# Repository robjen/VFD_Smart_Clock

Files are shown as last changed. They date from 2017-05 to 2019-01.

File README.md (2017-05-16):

# VFD_Smart_Clock

A Series of 'socket' designs and firmware running on ESP8266 for IoT smart clock

first draft of working firmware :
https://www.youtube.com/watch?v=jQWC35hEyko

Sockets are 1-4 digits in all sorts of size based on:
* 4 digits IV4/17 16 segment tube
* 1 digit 5x7 IV26 7 point tubes type 1 (fully independant dots) and type 3  (1-2-1-2-1 )
* 2 digits 2x 5x7 IV25 7 point tubes type 1 and type 3 (yes found these on the internet named them as above)
* LED lighting under/behind each tube with a WS2812 RGB 
* HV module on each board so they are fully independant and run from a single 5V supply
* 4 digital lines for easy control passed though each board SPI-clk SPI-data SPI-load BLANK LED-data

Any of the types of socket can be chained, but you might have to mess about with the firmware if you want mix-n-match different types

Firmware provides:
* clock display 
* NTP sync
* auto DST based on timezone
* hidden 'phrases'
* RSS news reader (BBC)
* Ability to add user messages
* Web interface for configuration
* a load of animated transitions and effects
* a few LED effects (more coming soon)

loads of new features coming soon

its a bit of a mess right now but in progress

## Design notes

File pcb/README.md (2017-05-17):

# eagle cad files for 5 types of PCB

not the best naming convention but load them to see whats what

all of them have been sent off for manufacture at http://dirtypcbs.com and work

simple layout for easy hand soldering including everything in sockets

I switched convention on the IV25 and started calling them type 1 and type 3 to match the IV26 tubes the PCB mask layer reflects that even if the PCB schematic does not

# Tubes ....

well they are getting harder to find but ebay is your friend, also use the 'international' .com site as I find the UK site sometimes hides possible sellers that will still ship to here and quote prices in dollars

# Components 

the main IC ... you can use that maxim part but its pricey or a perfect substitute is the 'HV5812' again ebay is the place to find those

WS2812b again ebay cheap and easy to find in reels ready to solder, that and 1 capacitor are surface mount (on the IV4/17 board) easy enough with a steady hand

the DC-DC module was again an ebay thing (can you spot a trend here!)  there are loads of far east manufactures doing a module that should be about £1 including post per module.  you could use one module to power more than 1 PCB with a fly-lead thats up to you, keeping 1 module per PCB means you can mix and match anything you want. 

# BIG SOLDER TIP

The hardest part can be threading the tubes and getting them all nice and level.

Note the marker point on each PCB, sometimes this is the short (almost removed) pin, sometimes the longest pin, sometimes just a vague guide ... it will depend where you sourced your tubes from, check and check again before you solder as there is no going back. the PCB layout is as per data sheet but these tubes have an element of 'hand made' so not 100% perfect they should face forward give or take a tiny adjustment.

I found that for tubes with few wires it is easy enough to align them all by hand in one go and push whole tube down in one step.

For tubes with lots of wires (IV4/17) start by threading a few on one side then work round with tweezers loading each wire in turn until you can push the whole tube home.

DO NOT use the glass envelope of the tube to try and align the digits, they vary quite a lot internally so allow a gap above the PCB on the first one you solder and alight the 'dots' or digits by eye or with a rule to get them even. If you dont allow a gap on the first one you might find you cant push subsequent ones down low enough ... 

At this point in construction I tended to tape everything down to a spare board as I went so that all the tubes were well aligned and I can fip it up and solder

KEEP YOUR FIRST EXAMPLE at least the first one you are happy with, then you can use it as a guide of height of dot/digit from the PCB for subsequent builds  (I use a scrap early PCB design that had an error but the tubes are neat so its a good guide).

you can adjust tubes a little once soldered but there is a risk you will break the pins or short something if you try and squash the tubes down. you cant really do more than a tiny twist on the IV4/17 tubes

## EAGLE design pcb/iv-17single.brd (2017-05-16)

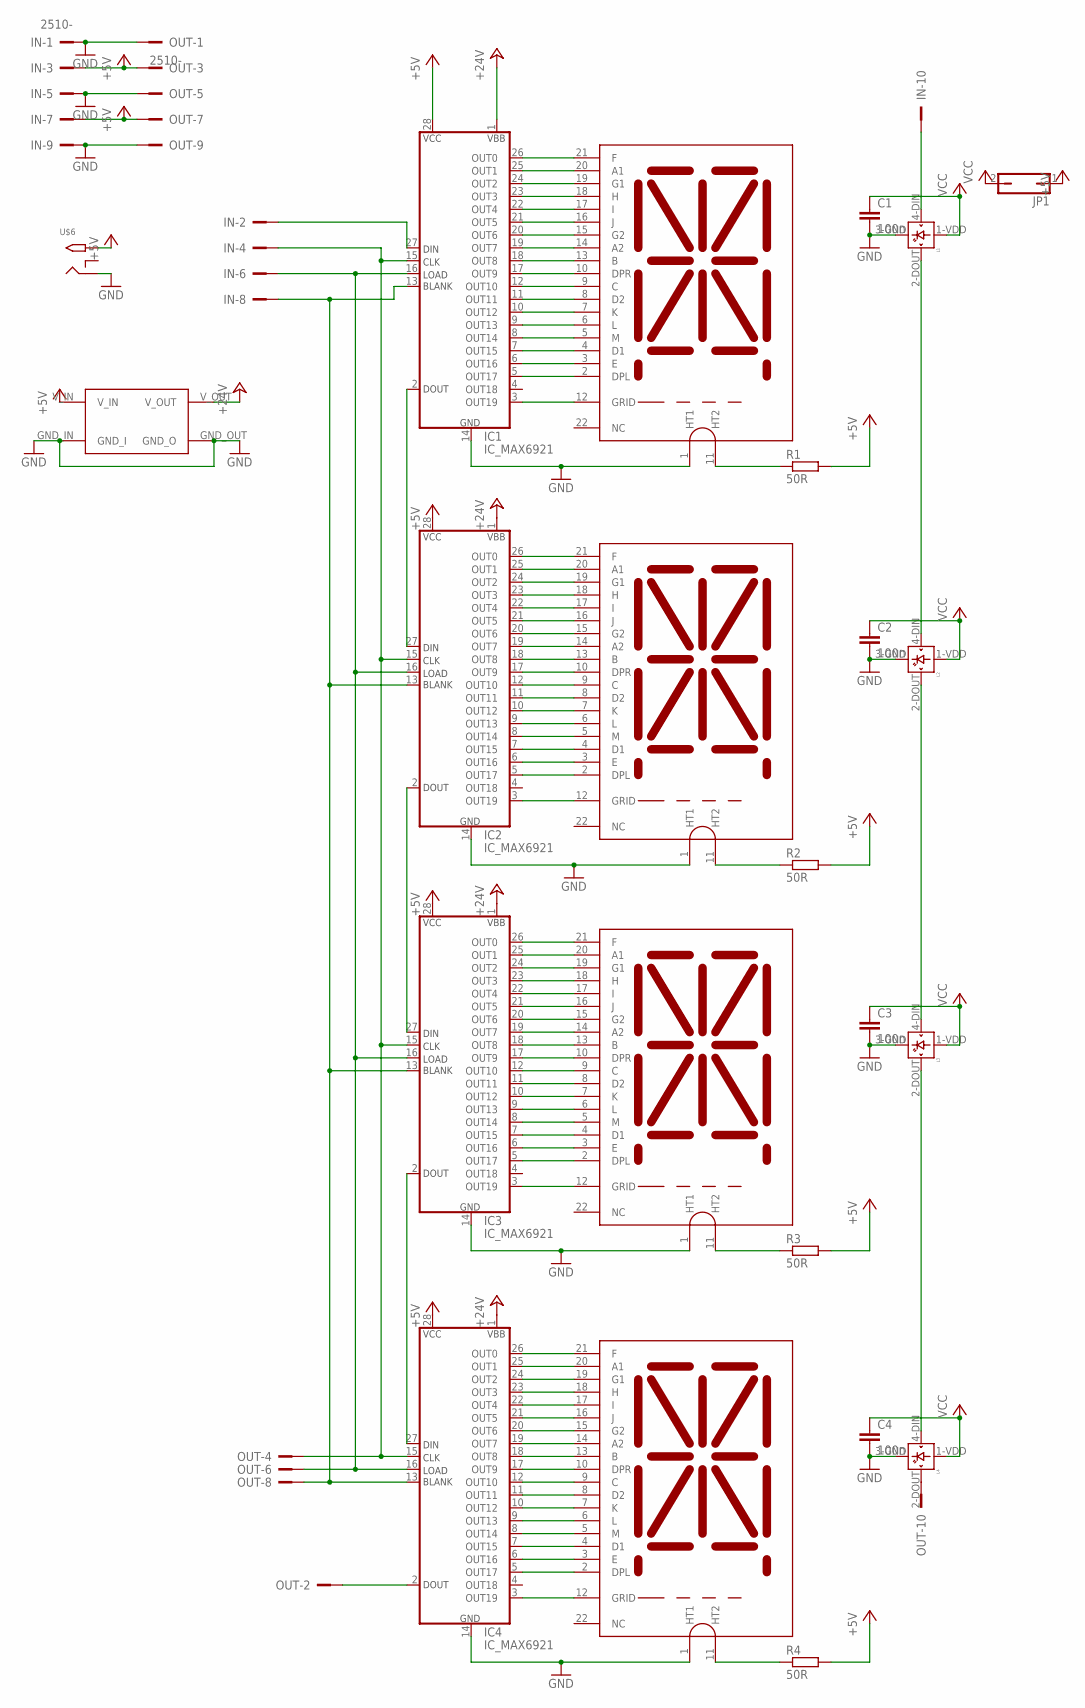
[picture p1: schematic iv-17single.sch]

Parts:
1, 2, 3, 4: IV-17_DISPIV-17; IV-17
C1, C2, C3, C4: 100n; C0805
IC1, IC2, IC3, IC4: IC_MAX6921; S28
IN: 2510-; PAK100/2500-10
JP1: JP1Q; JP1
L1, L2, L3, L4: WS2812B
OUT: 2510-; PAK100/2500-10
R1, R2, R3, R4: 50R; 0207/10
U$5: STEP_UP_MODULE
U$6: 2.1MMJACKTHM; PJ-102A

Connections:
+5V: IC1.28 (VCC), IC2.28 (VCC), IC3.28 (VCC), IC4.28 (VCC), IN.3, IN.7, JP1.1, OUT.3, OUT.7, R1.2, R2.2, R3.2, R4.2, U$5.V_IN, U$6.TIP
+24V: IC1.1 (VBB), IC2.1 (VBB), IC3.1 (VBB), IC4.1 (VBB), U$5.V_OUT
GND: 1.1 (HT1), 2.1 (HT1), 3.1 (HT1), 4.1 (HT1), C1.2, C2.2, C3.2, C4.2, IC1.14 (GND), IC2.14 (GND), IC3.14 (GND), IC4.14 (GND), IN.1, IN.5, IN.9, L1.3-GND (GND), L2.3-GND (GND), L3.3-GND (GND), L4.3-GND (GND), OUT.1, OUT.5, OUT.9, U$5.GND_IN (GND_I), U$5.GND_OUT (GND_O), U$6.RING
unnamed: 1.11 (HT2), R1.1
unnamed: 1.21 (F), IC1.26 (OUT0)
unnamed: 1.20 (A1), IC1.25 (OUT1)
unnamed: 1.19 (G1), IC1.24 (OUT2)
unnamed: 1.18 (H), IC1.23 (OUT3)
unnamed: 1.17 (I), IC1.22 (OUT4)
unnamed: 1.16 (J), IC1.21 (OUT5)
unnamed: 1.15 (G2), IC1.20 (OUT6)
unnamed: 1.14 (A2), IC1.19 (OUT7)
unnamed: 1.13 (B), IC1.18 (OUT8)
unnamed: 1.10 (DPR), IC1.17 (OUT9)
unnamed: 1.9 (C), IC1.12 (OUT10)
unnamed: 1.8 (D2), IC1.11 (OUT11)
unnamed: 1.7 (K), IC1.10 (OUT12)
unnamed: 1.6 (L), IC1.9 (OUT13)
unnamed: 1.5 (M), IC1.8 (OUT14)
unnamed: 1.4 (D1), IC1.7 (OUT15)
unnamed: 1.3 (E), IC1.6 (OUT16)
unnamed: 1.2 (DPL), IC1.5 (OUT17)
unnamed: 1.12 (GRID), IC1.3 (OUT19)
unnamed: IC1.27 (DIN), IN.2
unnamed: IC4.2 (DOUT), OUT.2
unnamed: 2.21 (F), IC2.26 (OUT0)
unnamed: L1.2-DOUT (DOUT), L2.4-DIN (DIN)
unnamed: IC1.2 (DOUT), IC2.27 (DIN)
unnamed: 2.20 (A1), IC2.25 (OUT1)
unnamed: 2.19 (G1), IC2.24 (OUT2)
unnamed: 2.18 (H), IC2.23 (OUT3)
unnamed: 2.17 (I), IC2.22 (OUT4)
unnamed: 2.16 (J), IC2.21 (OUT5)
unnamed: 2.15 (G2), IC2.20 (OUT6)
unnamed: 2.14 (A2), IC2.19 (OUT7)
unnamed: 2.13 (B), IC2.18 (OUT8)
unnamed: 2.10 (DPR), IC2.17 (OUT9)
unnamed: 2.9 (C), IC2.12 (OUT10)
unnamed: IC1.15 (CLK), IC2.15 (CLK), IC3.15 (CLK), IC4.15 (CLK), IN.4, OUT.4
unnamed: 2.8 (D2), IC2.11 (OUT11)
unnamed: 2.7 (K), IC2.10 (OUT12)
unnamed: 2.6 (L), IC2.9 (OUT13)
unnamed: 2.5 (M), IC2.8 (OUT14)
unnamed: 2.4 (D1), IC2.7 (OUT15)
unnamed: 2.3 (E), IC2.6 (OUT16)
unnamed: 2.2 (DPL), IC2.5 (OUT17)
unnamed: 2.12 (GRID), IC2.3 (OUT19)
unnamed: IC1.16 (LOAD), IC2.16 (LOAD), IC3.16 (LOAD), IC4.16 (LOAD), IN.6, OUT.6
unnamed: 2.11 (HT2), R2.1
unnamed: 3.21 (F), IC3.26 (OUT0)
unnamed: 3.20 (A1), IC3.25 (OUT1)
unnamed: 3.19 (G1), IC3.24 (OUT2)
unnamed: 3.18 (H), IC3.23 (OUT3)
unnamed: 3.17 (I), IC3.22 (OUT4)
unnamed: 3.16 (J), IC3.21 (OUT5)
unnamed: 3.15 (G2), IC3.20 (OUT6)
unnamed: 3.14 (A2), IC3.19 (OUT7)
unnamed: 3.13 (B), IC3.18 (OUT8)
unnamed: 3.10 (DPR), IC3.17 (OUT9)
unnamed: 3.9 (C), IC3.12 (OUT10)
unnamed: 3.8 (D2), IC3.11 (OUT11)
unnamed: 3.7 (K), IC3.10 (OUT12)
unnamed: 3.6 (L), IC3.9 (OUT13)
unnamed: 3.5 (M), IC3.8 (OUT14)
unnamed: 3.4 (D1), IC3.7 (OUT15)
unnamed: 3.3 (E), IC3.6 (OUT16)
unnamed: 3.2 (DPL), IC3.5 (OUT17)
unnamed: 3.12 (GRID), IC3.3 (OUT19)
unnamed: IC1.13 (BLANK), IC2.13 (BLANK), IC3.13 (BLANK), IC4.13 (BLANK), IN.8, OUT.8
unnamed: 3.11 (HT2), R3.1
unnamed: 4.21 (F), IC4.26 (OUT0)
unnamed: 4.20 (A1), IC4.25 (OUT1)
unnamed: 4.19 (G1), IC4.24 (OUT2)
unnamed: 4.18 (H), IC4.23 (OUT3)
unnamed: 4.17 (I), IC4.22 (OUT4)
unnamed: 4.16 (J), IC4.21 (OUT5)
unnamed: 4.15 (G2), IC4.20 (OUT6)
unnamed: 4.14 (A2), IC4.19 (OUT7)
unnamed: 4.13 (B), IC4.18 (OUT8)
unnamed: 4.10 (DPR), IC4.17 (OUT9)
unnamed: 4.9 (C), IC4.12 (OUT10)
unnamed: 4.8 (D2), IC4.11 (OUT11)
unnamed: 4.7 (K), IC4.10 (OUT12)
unnamed: 4.6 (L), IC4.9 (OUT13)
unnamed: 4.5 (M), IC4.8 (OUT14)
unnamed: 4.4 (D1), IC4.7 (OUT15)
unnamed: 4.3 (E), IC4.6 (OUT16)
unnamed: 4.2 (DPL), IC4.5 (OUT17)
unnamed: 4.12 (GRID), IC4.3 (OUT19)
unnamed: L2.2-DOUT (DOUT), L3.4-DIN (DIN)
unnamed: 4.11 (HT2), R4.1
unnamed: L3.2-DOUT (DOUT), L4.4-DIN (DIN)
unnamed: IN.10, L1.4-DIN (DIN)
unnamed: L4.2-DOUT (DOUT), OUT.10
unnamed: IC2.2 (DOUT), IC3.27 (DIN)
unnamed: IC3.2 (DOUT), IC4.27 (DIN)
VCC: C1.1, C2.1, C3.1, C4.1, JP1.2, L1.1-VDD (VDD), L2.1-VDD (VDD), L3.1-VDD (VDD), L4.1-VDD (VDD)

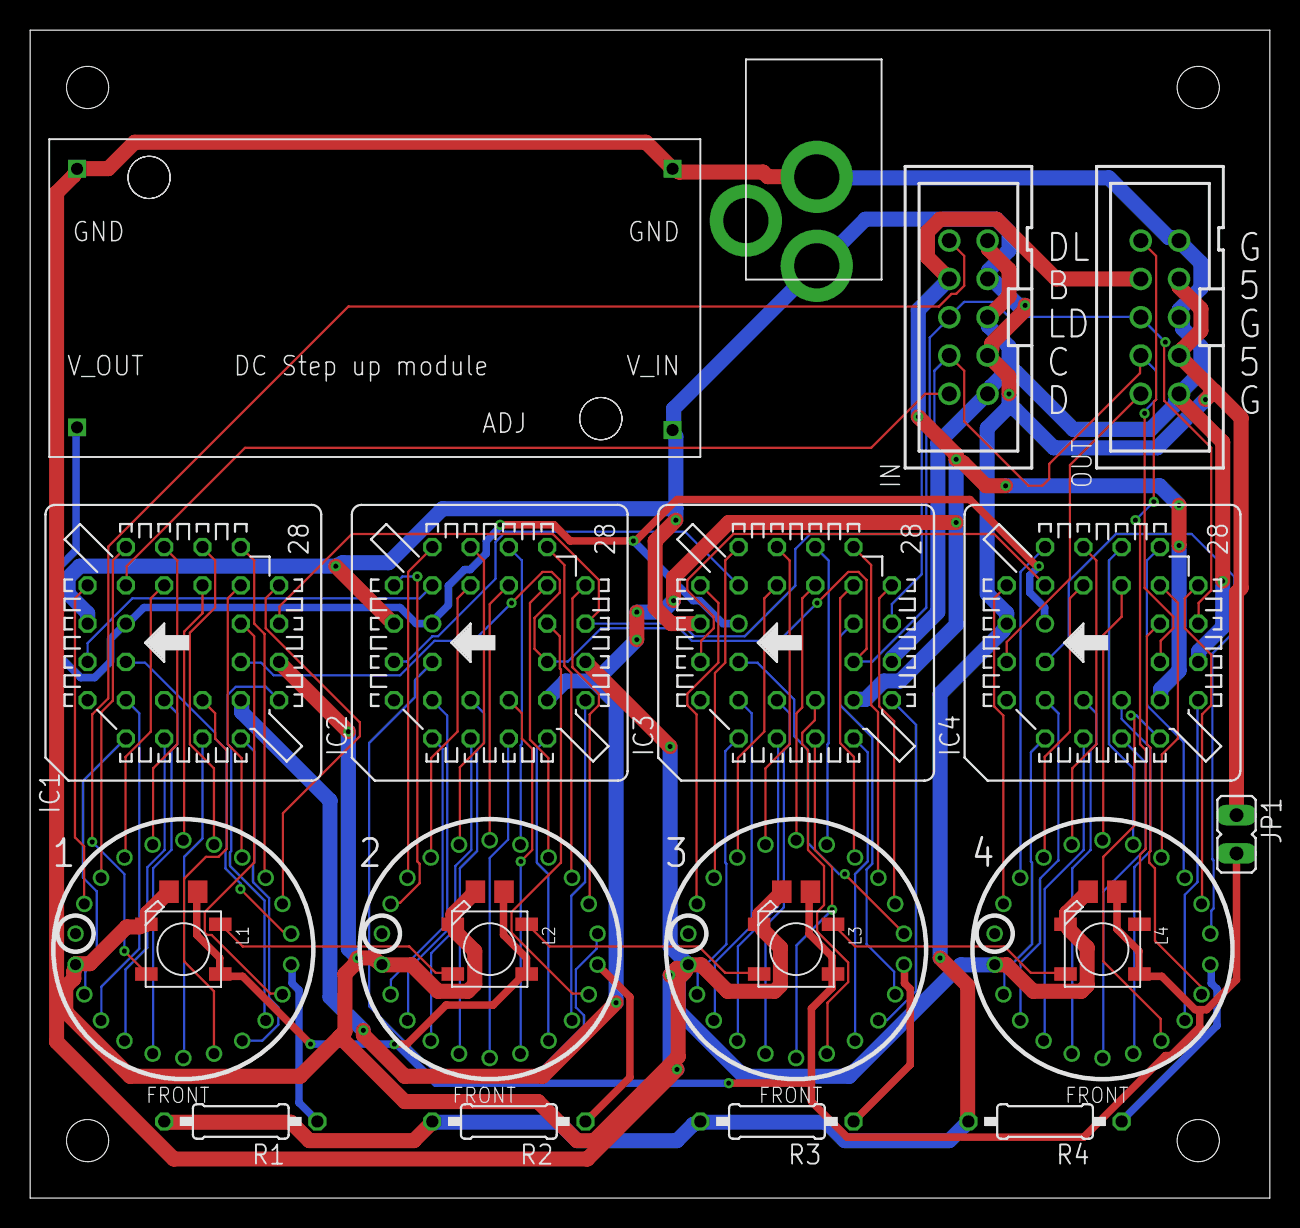
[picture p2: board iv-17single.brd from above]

Board: 2 copper layers, 82.2 x 77.5 mm, 25 parts (0 on the bottom side), 97 nets.

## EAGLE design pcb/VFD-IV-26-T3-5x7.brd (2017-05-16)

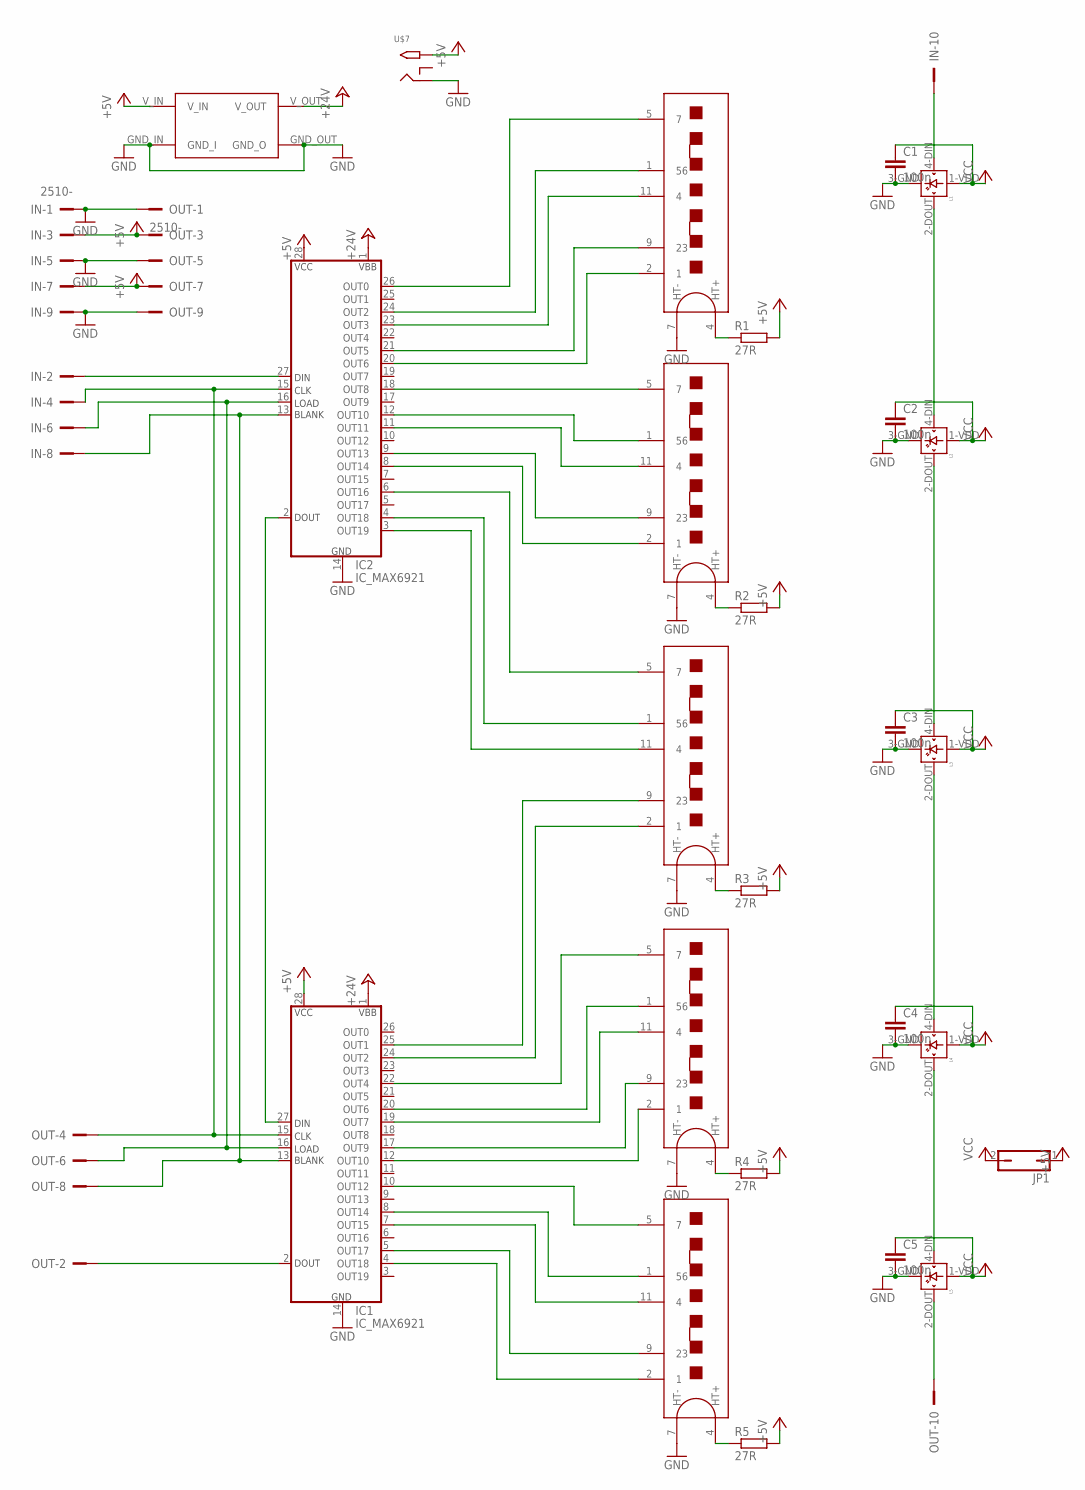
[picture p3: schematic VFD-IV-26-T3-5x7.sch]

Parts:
1, 2, 3, 4, 5: IV-26-T3_DISP; IV-26_T2_T3
C1, C2, C3, C4, C5: 100n; C050-025X075
IC1, IC2: IC_MAX6921; S28
IN: 2510-; PAK100/2500-10
JP1: JP1Q; JP1
L1, L2, L3, L4, L5: WS2812B
OUT: 2510-; PAK100/2500-10
R1, R2, R3, R4, R5: 27R; 0207/10
U$6: STEP_UP_MODULE
U$7: 2.1MMJACKTHM; PJ-102A

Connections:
+5V: IC1.28 (VCC), IC2.28 (VCC), IN.3, IN.7, JP1.1, OUT.3, OUT.7, R1.2, R2.2, R3.2, R4.2, R5.2, U$6.V_IN, U$7.TIP
+24V: IC1.1 (VBB), IC2.1 (VBB), U$6.V_OUT
GND: 1.7 (HT-), 2.7 (HT-), 3.7 (HT-), 4.7 (HT-), 5.7 (HT-), C1.2, C2.2, C3.2, C4.2, C5.2, IC1.14 (GND), IC2.14 (GND), IN.1, IN.5, IN.9, L1.3-GND (GND), L2.3-GND (GND), L3.3-GND (GND), L4.3-GND (GND), L5.3-GND (GND), OUT.1, OUT.5, OUT.9, U$6.GND_IN (GND_I), U$6.GND_OUT (GND_O), U$7.RING
unnamed: 1.5 (7), IC2.26 (OUT0)
unnamed: 1.1 (56), IC2.24 (OUT2)
unnamed: 1.11 (4), IC2.23 (OUT3)
unnamed: 1.9 (23), IC2.21 (OUT5)
unnamed: 1.2 (1), IC2.20 (OUT6)
unnamed: 2.5 (7), IC2.18 (OUT8)
unnamed: 2.1 (56), IC2.12 (OUT10)
unnamed: 2.11 (4), IC2.11 (OUT11)
unnamed: 2.9 (23), IC2.9 (OUT13)
unnamed: 2.2 (1), IC2.8 (OUT14)
unnamed: 3.5 (7), IC2.6 (OUT16)
unnamed: 3.1 (56), IC2.4 (OUT18)
unnamed: 3.11 (4), IC2.3 (OUT19)
unnamed: 3.9 (23), IC1.25 (OUT1)
unnamed: 3.2 (1), IC1.24 (OUT2)
unnamed: 4.5 (7), IC1.22 (OUT4)
unnamed: 4.1 (56), IC1.20 (OUT6)
unnamed: 4.11 (4), IC1.19 (OUT7)
unnamed: 4.9 (23), IC1.17 (OUT9)
unnamed: 4.2 (1), IC1.12 (OUT10)
unnamed: 5.5 (7), IC1.10 (OUT12)
unnamed: 5.1 (56), IC1.8 (OUT14)
unnamed: 5.11 (4), IC1.7 (OUT15)
unnamed: 5.9 (23), IC1.5 (OUT17)
unnamed: 5.2 (1), IC1.4 (OUT18)
unnamed: L1.2-DOUT (DOUT), L2.4-DIN (DIN)
unnamed: L2.2-DOUT (DOUT), L3.4-DIN (DIN)
unnamed: L3.2-DOUT (DOUT), L4.4-DIN (DIN)
unnamed: L4.2-DOUT (DOUT), L5.4-DIN (DIN)
unnamed: IC1.15 (CLK), IC2.15 (CLK), IN.4, OUT.4
unnamed: IC1.27 (DIN), IC2.2 (DOUT)
unnamed: IC1.13 (BLANK), IC2.13 (BLANK), IN.8, OUT.8
unnamed: IC1.16 (LOAD), IC2.16 (LOAD), IN.6, OUT.6
unnamed: IC2.27 (DIN), IN.2
unnamed: IN.10, L1.4-DIN (DIN)
unnamed: 2.4 (HT+), R2.1
unnamed: 3.4 (HT+), R3.1
unnamed: 4.4 (HT+), R4.1
unnamed: 5.4 (HT+), R5.1
unnamed: 1.4 (HT+), R1.1
unnamed: IC1.2 (DOUT), OUT.2
unnamed: L5.2-DOUT (DOUT), OUT.10
VCC: C1.1, C2.1, C3.1, C4.1, C5.1, JP1.2, L1.1-VDD (VDD), L2.1-VDD (VDD), L3.1-VDD (VDD), L4.1-VDD (VDD), L5.1-VDD (VDD)

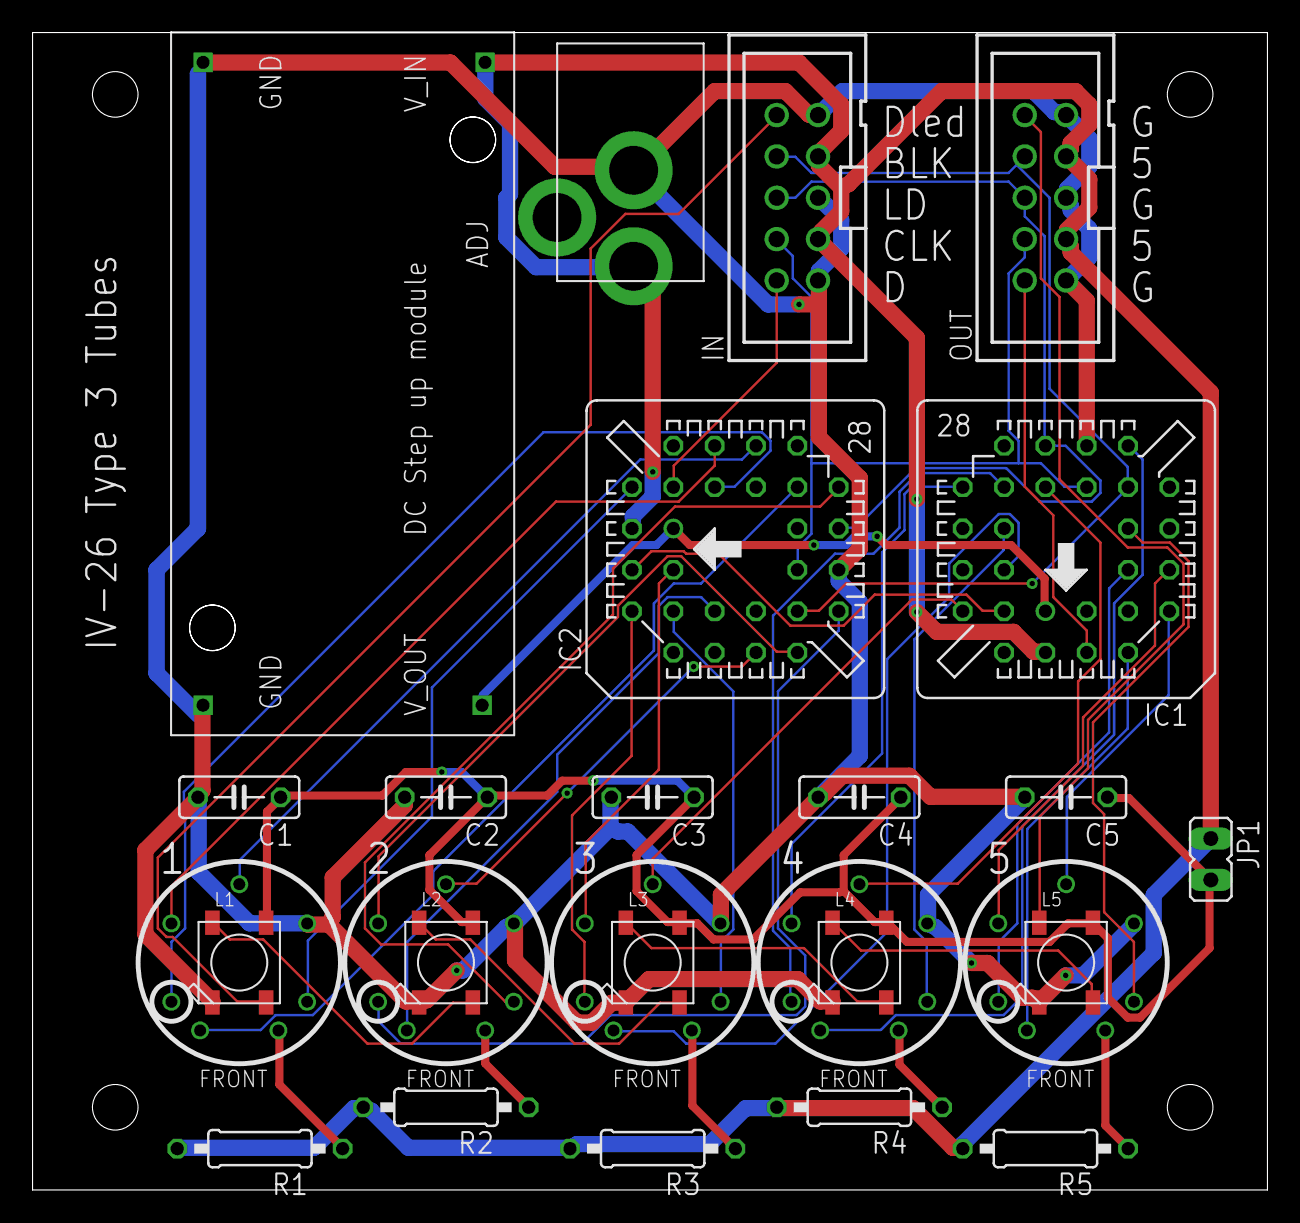
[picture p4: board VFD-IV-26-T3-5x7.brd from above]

Board: 2 copper layers, 75.9 x 71.1 mm, 27 parts (0 on the bottom side), 46 nets.

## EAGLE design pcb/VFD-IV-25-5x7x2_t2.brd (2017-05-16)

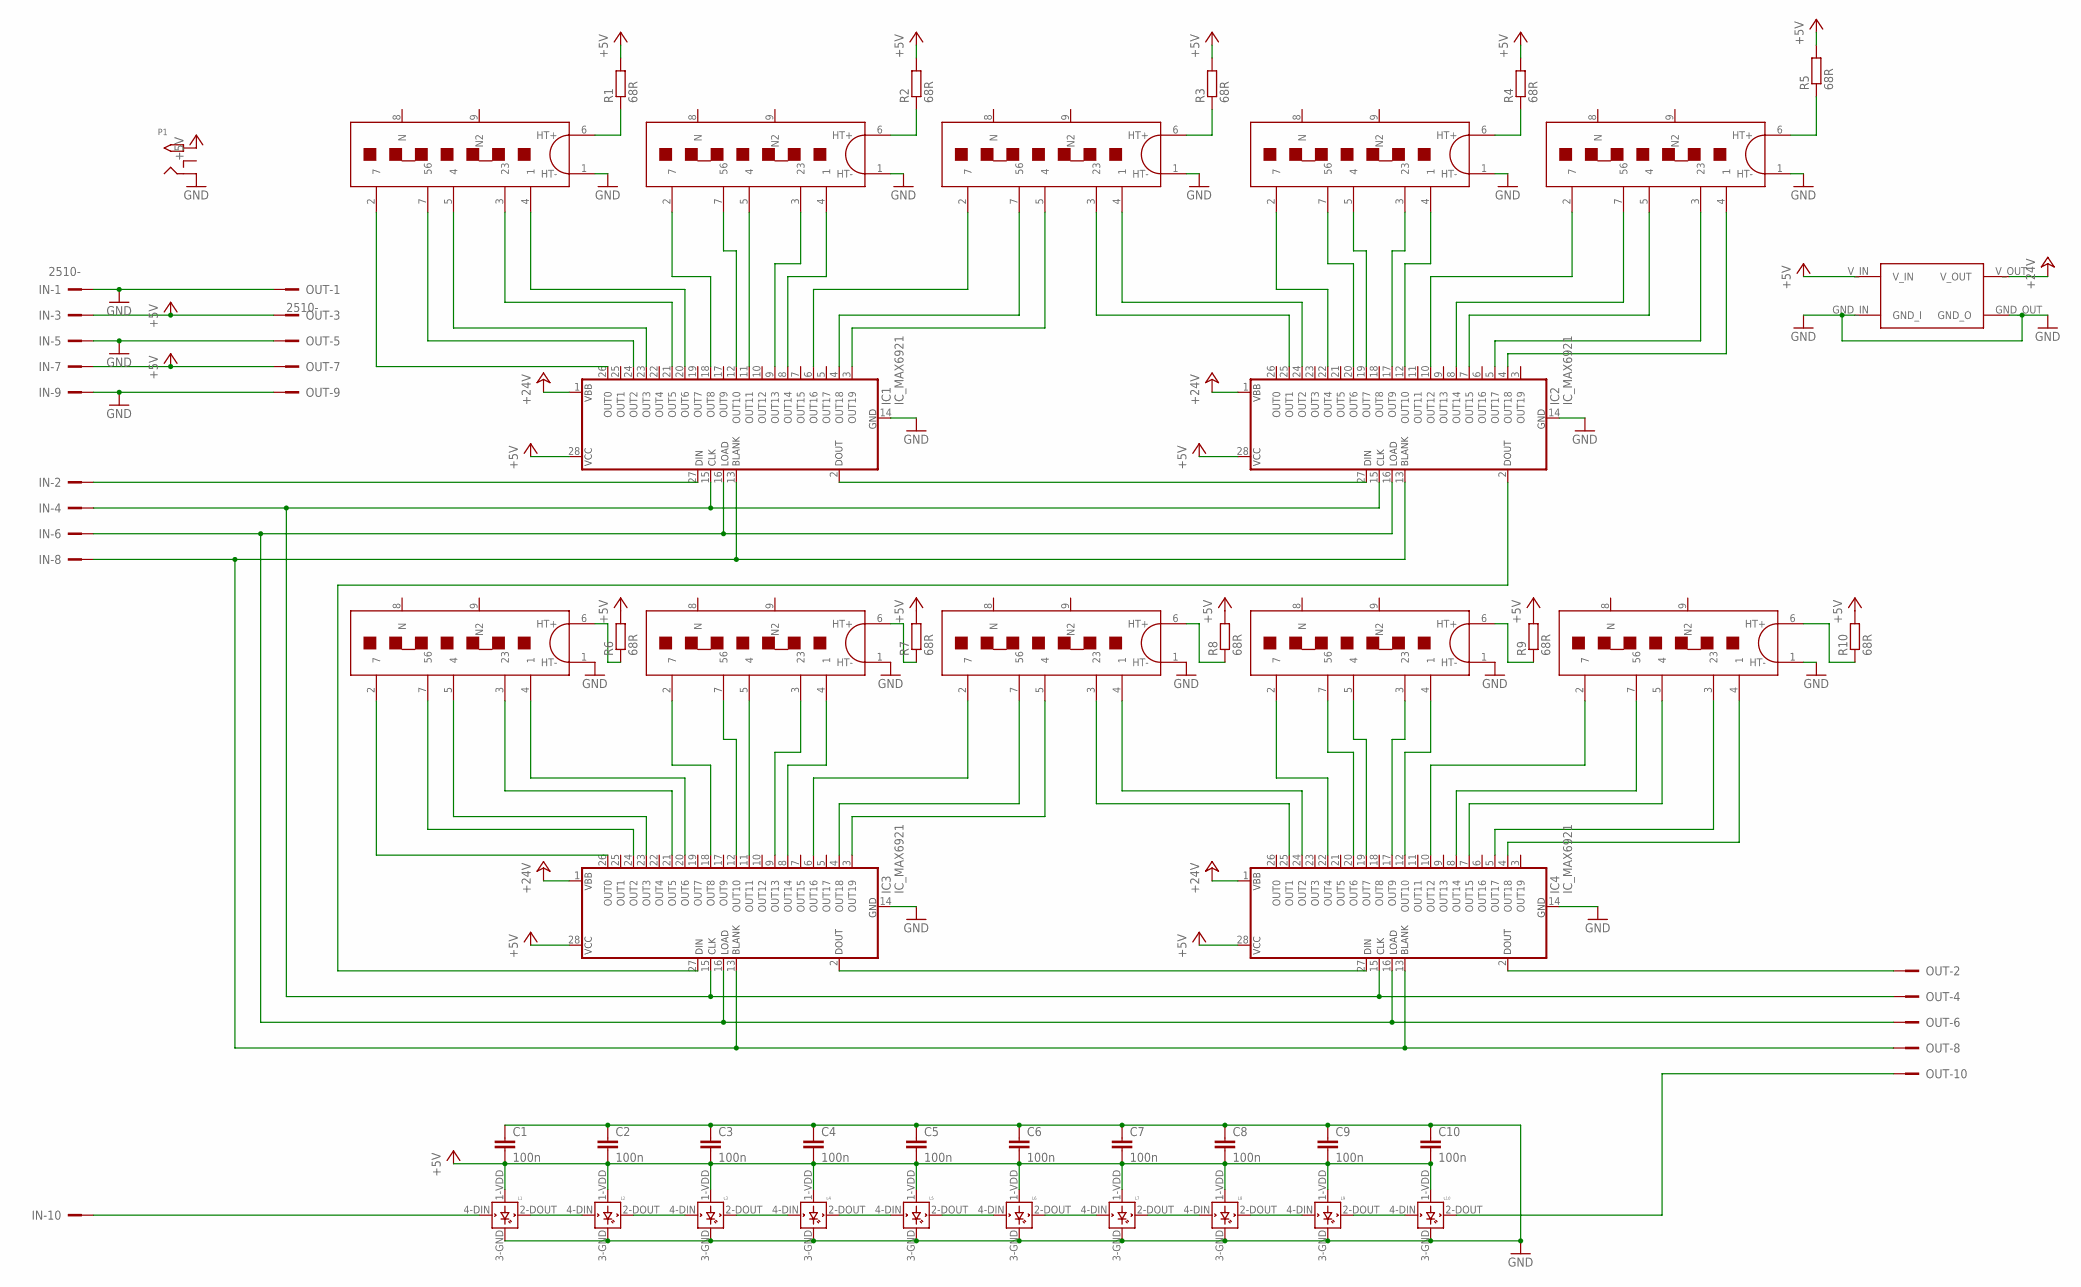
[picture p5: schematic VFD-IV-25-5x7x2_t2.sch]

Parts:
1, 2, 3, 4, 5, 6, 7, 8, 9, 10: IV-25_DISP_T3; IV-25
C1, C2, C3, C4, C5, C6, C7, C8, C9, C10: 100n; C050-025X075
IC1, IC2, IC3, IC4: IC_MAX6921; S28
IN: 2510-; PAK100/2500-10
L1, L2, L3, L4, L5, L6, L7, L8, L9, L10: WS2812B
OUT: 2510-; PAK100/2500-10
P1: 2.1MMJACKTHM; PJ-102A
R1, R2, R3, R4, R5, R6, R7, R8, R9, R10: 68R; 0207/10
U$11: STEP_UP_MODULE

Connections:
+5V: C1.2, C2.2, C3.2, C4.2, C5.2, C6.2, C7.2, C8.2, C9.2, C10.2, IC1.28 (VCC), IC2.28 (VCC), IC3.28 (VCC), IC4.28 (VCC), IN.3, IN.7, L1.1-VDD (VDD), L2.1-VDD (VDD), L3.1-VDD (VDD), L4.1-VDD (VDD), L5.1-VDD (VDD), L6.1-VDD (VDD), L7.1-VDD (VDD), L8.1-VDD (VDD), L9.1-VDD (VDD), L10.1-VDD (VDD), OUT.3, OUT.7, P1.TIP, R1.2, R2.2, R3.2, R4.2, R5.2, R6.2, R7.2, R8.2, R9.2, R10.2, U$11.V_IN
+24V: IC1.1 (VBB), IC2.1 (VBB), IC3.1 (VBB), IC4.1 (VBB), U$11.V_OUT
GND: 1.1 (HT-), 2.1 (HT-), 3.1 (HT-), 4.1 (HT-), 5.1 (HT-), 6.1 (HT-), 7.1 (HT-), 8.1 (HT-), 9.1 (HT-), 10.1 (HT-), C1.1, C2.1, C3.1, C4.1, C5.1, C6.1, C7.1, C8.1, C9.1, C10.1, IC1.14 (GND), IC2.14 (GND), IC3.14 (GND), IC4.14 (GND), IN.1, IN.5, IN.9, L1.3-GND (GND), L2.3-GND (GND), L3.3-GND (GND), L4.3-GND (GND), L5.3-GND (GND), L6.3-GND (GND), L7.3-GND (GND), L8.3-GND (GND), L9.3-GND (GND), L10.3-GND (GND), OUT.1, OUT.5, OUT.9, P1.RING, U$11.GND_IN (GND_I), U$11.GND_OUT (GND_O)
unnamed: L1.2-DOUT (DOUT), L2.4-DIN (DIN)
unnamed: L2.2-DOUT (DOUT), L3.4-DIN (DIN)
unnamed: L3.2-DOUT (DOUT), L4.4-DIN (DIN)
unnamed: L4.2-DOUT (DOUT), L5.4-DIN (DIN)
unnamed: L5.2-DOUT (DOUT), L6.4-DIN (DIN)
unnamed: L6.2-DOUT (DOUT), L7.4-DIN (DIN)
unnamed: L7.2-DOUT (DOUT), L8.4-DIN (DIN)
unnamed: L8.2-DOUT (DOUT), L9.4-DIN (DIN)
unnamed: L9.2-DOUT (DOUT), L10.4-DIN (DIN)
unnamed: 1.2 (7), IC1.26 (OUT0)
unnamed: 1.7 (56), IC1.24 (OUT2)
unnamed: 1.5 (4), IC1.23 (OUT3)
unnamed: 1.3 (23), IC1.21 (OUT5)
unnamed: 1.4 (1), IC1.20 (OUT6)
unnamed: 2.2 (7), IC1.18 (OUT8)
unnamed: 2.7 (56), IC1.12 (OUT10)
unnamed: 2.5 (4), IC1.11 (OUT11)
unnamed: 2.3 (23), IC1.9 (OUT13)
unnamed: 2.4 (1), IC1.8 (OUT14)
unnamed: 3.2 (7), IC1.6 (OUT16)
unnamed: 4.2 (7), IC2.22 (OUT4)
unnamed: 3.7 (56), IC1.4 (OUT18)
unnamed: 3.5 (4), IC1.3 (OUT19)
unnamed: 3.3 (23), IC2.25 (OUT1)
unnamed: 3.4 (1), IC2.24 (OUT2)
unnamed: 4.7 (56), IC2.20 (OUT6)
unnamed: 4.5 (4), IC2.19 (OUT7)
unnamed: 4.3 (23), IC2.17 (OUT9)
unnamed: 4.4 (1), IC2.12 (OUT10)
unnamed: 5.2 (7), IC2.10 (OUT12)
unnamed: 5.7 (56), IC2.8 (OUT14)
unnamed: 5.5 (4), IC2.7 (OUT15)
unnamed: 5.3 (23), IC2.5 (OUT17)
unnamed: 5.4 (1), IC2.4 (OUT18)
unnamed: 6.2 (7), IC3.26 (OUT0)
unnamed: 6.7 (56), IC3.24 (OUT2)
unnamed: 6.5 (4), IC3.23 (OUT3)
unnamed: 6.3 (23), IC3.21 (OUT5)
unnamed: 6.4 (1), IC3.20 (OUT6)
unnamed: 7.2 (7), IC3.18 (OUT8)
unnamed: 7.7 (56), IC3.12 (OUT10)
unnamed: 7.5 (4), IC3.11 (OUT11)
unnamed: 7.3 (23), IC3.9 (OUT13)
unnamed: 7.4 (1), IC3.8 (OUT14)
unnamed: 8.2 (7), IC3.6 (OUT16)
unnamed: 8.7 (56), IC3.4 (OUT18)
unnamed: 8.5 (4), IC3.3 (OUT19)
unnamed: 8.3 (23), IC4.25 (OUT1)
unnamed: 8.4 (1), IC4.24 (OUT2)
unnamed: 9.2 (7), IC4.22 (OUT4)
unnamed: 9.7 (56), IC4.20 (OUT6)
unnamed: 9.5 (4), IC4.19 (OUT7)
unnamed: 9.3 (23), IC4.17 (OUT9)
unnamed: 9.4 (1), IC4.12 (OUT10)
unnamed: 10.2 (7), IC4.10 (OUT12)
unnamed: 10.7 (56), IC4.8 (OUT14)
unnamed: 10.5 (4), IC4.7 (OUT15)
unnamed: 10.3 (23), IC4.5 (OUT17)
unnamed: 10.4 (1), IC4.4 (OUT18)
unnamed: IC1.2 (DOUT), IC2.27 (DIN)
unnamed: IC2.2 (DOUT), IC3.27 (DIN)
unnamed: IC3.2 (DOUT), IC4.27 (DIN)
unnamed: IC1.27 (DIN), IN.2
unnamed: IN.10, L1.4-DIN (DIN)
unnamed: L10.2-DOUT (DOUT), OUT.10
unnamed: IC4.2 (DOUT), OUT.2
unnamed: IC1.15 (CLK), IC2.15 (CLK), IC3.15 (CLK), IC4.15 (CLK), IN.4, OUT.4
unnamed: IC1.16 (LOAD), IC2.16 (LOAD), IC3.16 (LOAD), IC4.16 (LOAD), IN.6, OUT.6
unnamed: 5.6 (HT+), R5.1
unnamed: IC1.13 (BLANK), IC2.13 (BLANK), IC3.13 (BLANK), IC4.13 (BLANK), IN.8, OUT.8
unnamed: 4.6 (HT+), R4.1
unnamed: 3.6 (HT+), R3.1
unnamed: 2.6 (HT+), R2.1
unnamed: 1.6 (HT+), R1.1
unnamed: 9.6 (HT+), R9.1
unnamed: 10.6 (HT+), R10.1
unnamed: 8.6 (HT+), R8.1
unnamed: 7.6 (HT+), R7.1
unnamed: 6.6 (HT+), R6.1

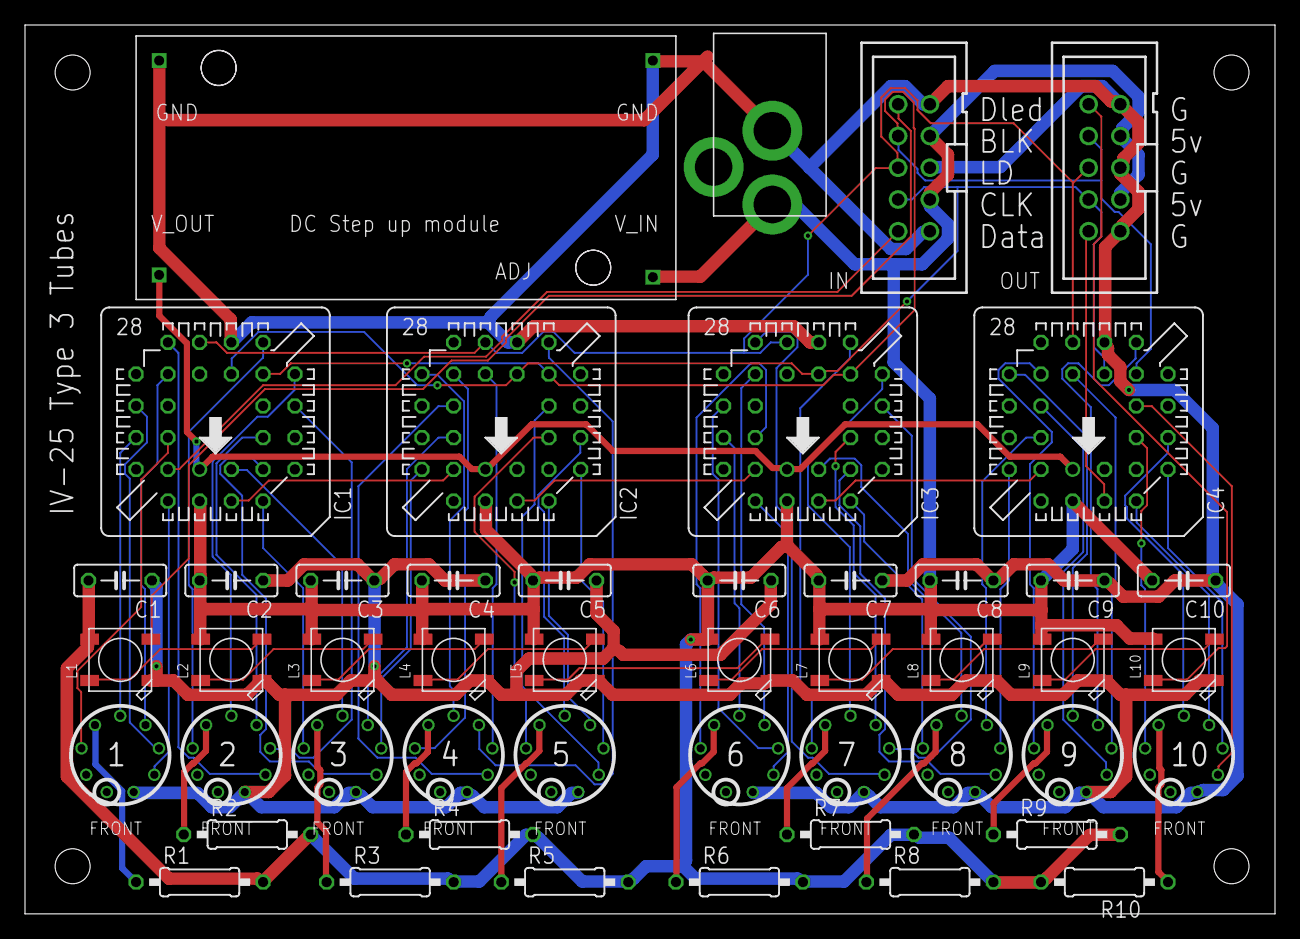
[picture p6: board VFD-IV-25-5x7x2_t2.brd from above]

Board: 2 copper layers, 100.0 x 71.1 mm, 48 parts (0 on the bottom side), 82 nets.

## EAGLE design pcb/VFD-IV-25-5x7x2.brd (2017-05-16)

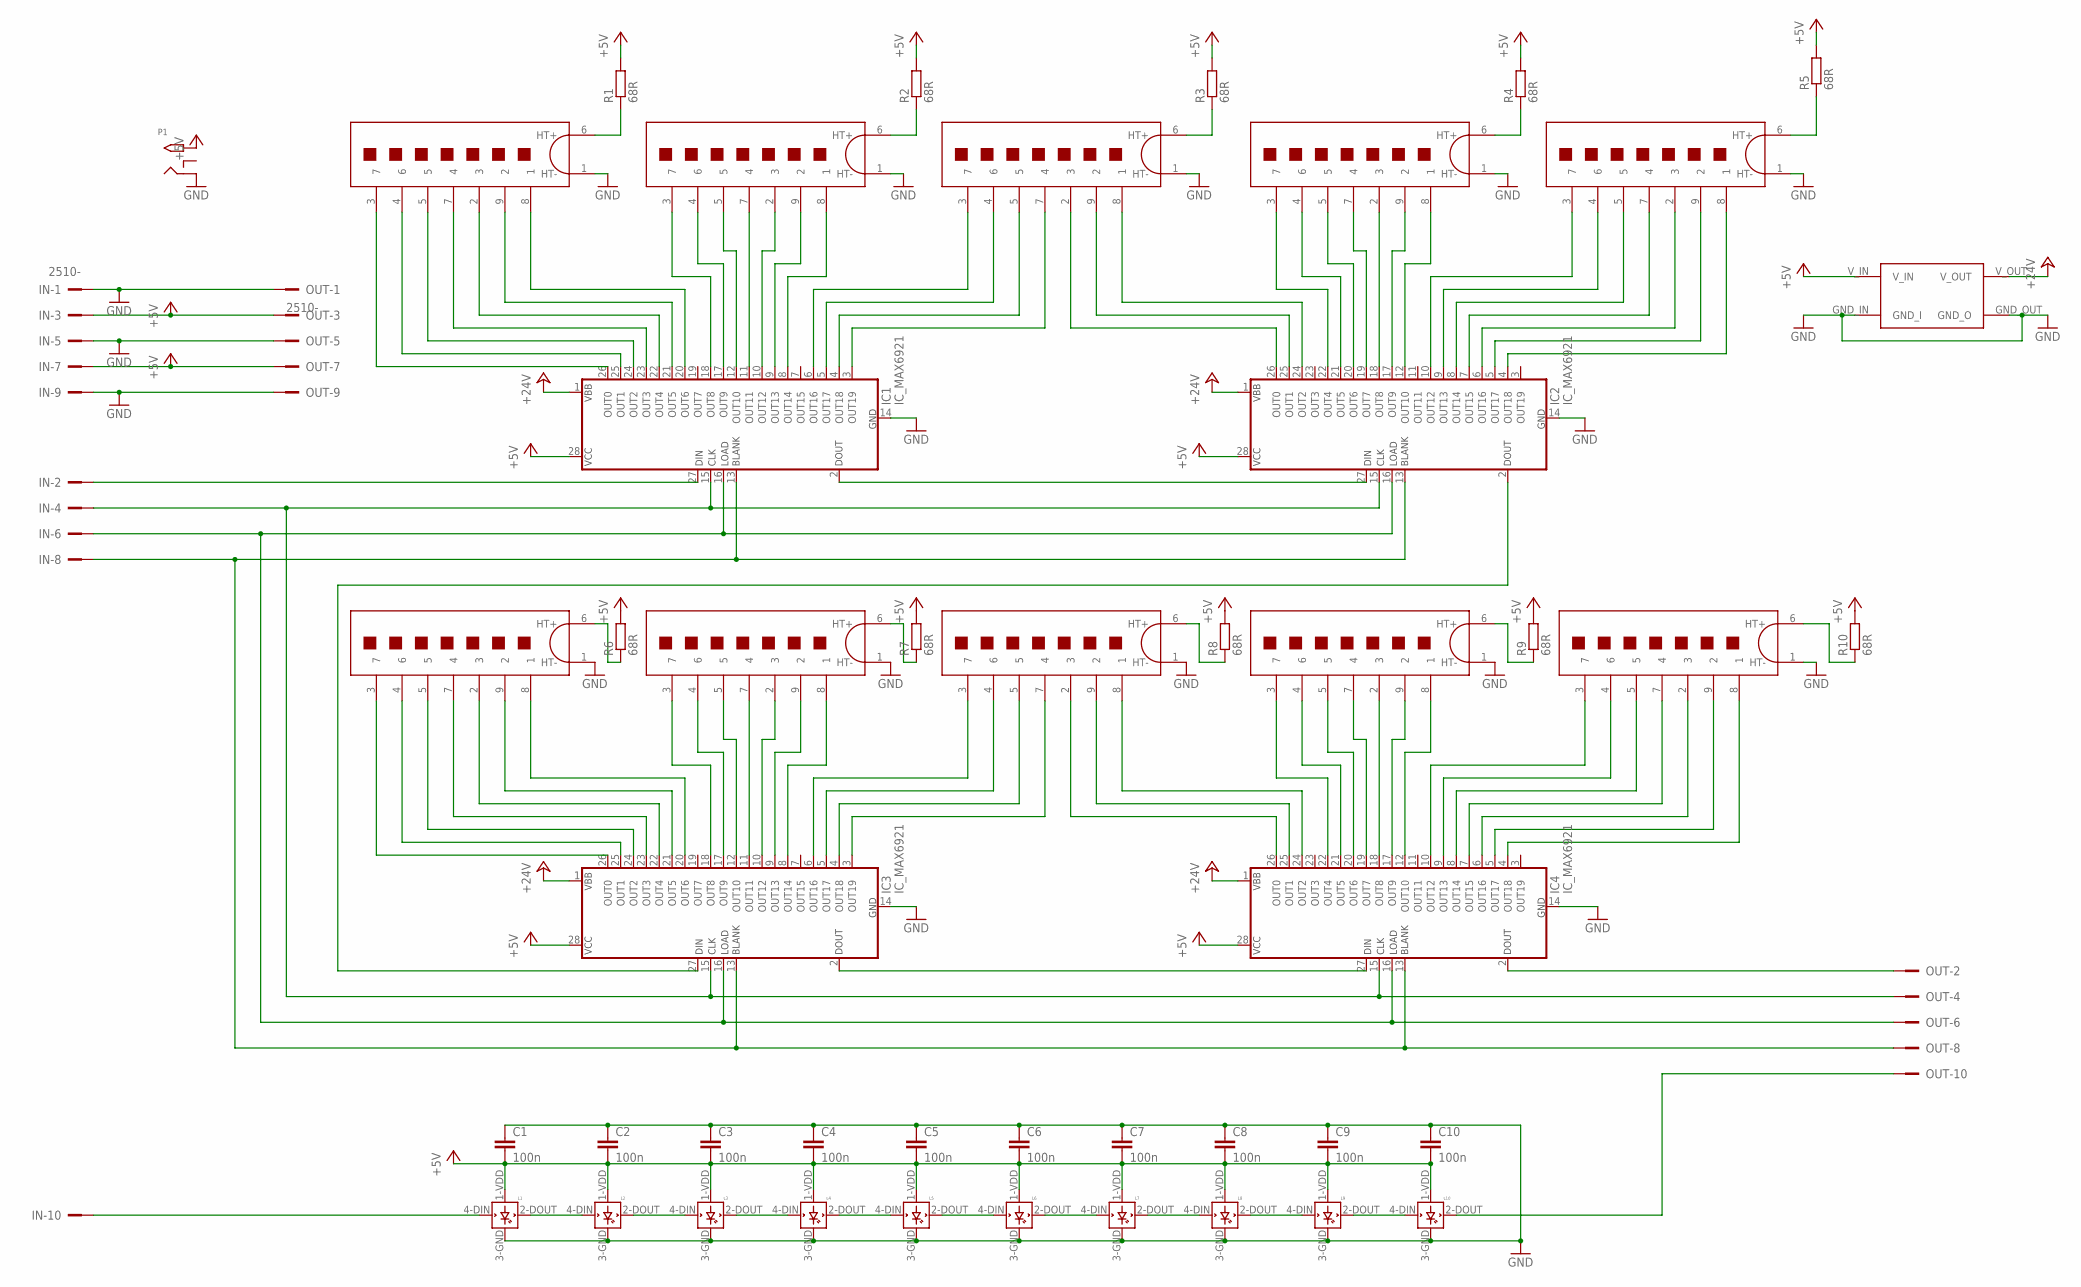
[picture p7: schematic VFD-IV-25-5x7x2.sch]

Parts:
1, 2, 3, 4, 5, 6, 7, 8, 9, 10: IV-25_DISP; IV-25
C1, C2, C3, C4, C5, C6, C7, C8, C9, C10: 100n; C050-025X075
IC1, IC2, IC3, IC4: IC_MAX6921; S28
IN: 2510-; PAK100/2500-10
L1, L2, L3, L4, L5, L6, L7, L8, L9, L10: WS2812B
OUT: 2510-; PAK100/2500-10
P1: 2.1MMJACKTHM; PJ-102A
R1, R2, R3, R4, R5, R6, R7, R8, R9, R10: 68R; 0207/10
U$11: STEP_UP_MODULE

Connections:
+5V: C1.2, C2.2, C3.2, C4.2, C5.2, C6.2, C7.2, C8.2, C9.2, C10.2, IC1.28 (VCC), IC2.28 (VCC), IC3.28 (VCC), IC4.28 (VCC), IN.3, IN.7, L1.1-VDD (VDD), L2.1-VDD (VDD), L3.1-VDD (VDD), L4.1-VDD (VDD), L5.1-VDD (VDD), L6.1-VDD (VDD), L7.1-VDD (VDD), L8.1-VDD (VDD), L9.1-VDD (VDD), L10.1-VDD (VDD), OUT.3, OUT.7, P1.TIP, R1.2, R2.2, R3.2, R4.2, R5.2, R6.2, R7.2, R8.2, R9.2, R10.2, U$11.V_IN
+24V: IC1.1 (VBB), IC2.1 (VBB), IC3.1 (VBB), IC4.1 (VBB), U$11.V_OUT
GND: 1.1 (HT-), 2.1 (HT-), 3.1 (HT-), 4.1 (HT-), 5.1 (HT-), 6.1 (HT-), 7.1 (HT-), 8.1 (HT-), 9.1 (HT-), 10.1 (HT-), C1.1, C2.1, C3.1, C4.1, C5.1, C6.1, C7.1, C8.1, C9.1, C10.1, IC1.14 (GND), IC2.14 (GND), IC3.14 (GND), IC4.14 (GND), IN.1, IN.5, IN.9, L1.3-GND (GND), L2.3-GND (GND), L3.3-GND (GND), L4.3-GND (GND), L5.3-GND (GND), L6.3-GND (GND), L7.3-GND (GND), L8.3-GND (GND), L9.3-GND (GND), L10.3-GND (GND), OUT.1, OUT.5, OUT.9, P1.RING, U$11.GND_IN (GND_I), U$11.GND_OUT (GND_O)
unnamed: L1.2-DOUT (DOUT), L2.4-DIN (DIN)
unnamed: L2.2-DOUT (DOUT), L3.4-DIN (DIN)
unnamed: L3.2-DOUT (DOUT), L4.4-DIN (DIN)
unnamed: L4.2-DOUT (DOUT), L5.4-DIN (DIN)
unnamed: L5.2-DOUT (DOUT), L6.4-DIN (DIN)
unnamed: L6.2-DOUT (DOUT), L7.4-DIN (DIN)
unnamed: L7.2-DOUT (DOUT), L8.4-DIN (DIN)
unnamed: L8.2-DOUT (DOUT), L9.4-DIN (DIN)
unnamed: L9.2-DOUT (DOUT), L10.4-DIN (DIN)
unnamed: 1.3 (7), IC1.26 (OUT0)
unnamed: 1.4 (6), IC1.25 (OUT1)
unnamed: 1.5, IC1.24 (OUT2)
unnamed: 1.7 (4), IC1.23 (OUT3)
unnamed: 1.2 (3), IC1.22 (OUT4)
unnamed: 1.9 (2), IC1.21 (OUT5)
unnamed: 1.8 (1), IC1.20 (OUT6)
unnamed: 2.3 (7), IC1.18 (OUT8)
unnamed: 2.4 (6), IC1.17 (OUT9)
unnamed: 2.5, IC1.12 (OUT10)
unnamed: 2.7 (4), IC1.11 (OUT11)
unnamed: 2.2 (3), IC1.10 (OUT12)
unnamed: 2.9 (2), IC1.9 (OUT13)
unnamed: 2.8 (1), IC1.8 (OUT14)
unnamed: 3.3 (7), IC1.6 (OUT16)
unnamed: 3.4 (6), IC1.5 (OUT17)
unnamed: 4.3 (7), IC2.22 (OUT4)
unnamed: 4.4 (6), IC2.21 (OUT5)
unnamed: 3.5, IC1.4 (OUT18)
unnamed: 3.7 (4), IC1.3 (OUT19)
unnamed: 3.2 (3), IC2.26 (OUT0)
unnamed: 3.9 (2), IC2.25 (OUT1)
unnamed: 3.8 (1), IC2.24 (OUT2)
unnamed: 4.5, IC2.20 (OUT6)
unnamed: 4.7 (4), IC2.19 (OUT7)
unnamed: 4.2 (3), IC2.18 (OUT8)
unnamed: 4.9 (2), IC2.17 (OUT9)
unnamed: 4.8 (1), IC2.12 (OUT10)
unnamed: 5.3 (7), IC2.10 (OUT12)
unnamed: 5.4 (6), IC2.9 (OUT13)
unnamed: 5.5, IC2.8 (OUT14)
unnamed: 5.7 (4), IC2.7 (OUT15)
unnamed: 5.2 (3), IC2.6 (OUT16)
unnamed: 5.9 (2), IC2.5 (OUT17)
unnamed: 5.8 (1), IC2.4 (OUT18)
unnamed: 6.3 (7), IC3.26 (OUT0)
unnamed: 6.4 (6), IC3.25 (OUT1)
unnamed: 6.5, IC3.24 (OUT2)
unnamed: 6.7 (4), IC3.23 (OUT3)
unnamed: 6.2 (3), IC3.22 (OUT4)
unnamed: 6.9 (2), IC3.21 (OUT5)
unnamed: 6.8 (1), IC3.20 (OUT6)
unnamed: 7.3 (7), IC3.18 (OUT8)
unnamed: 7.4 (6), IC3.17 (OUT9)
unnamed: 7.5, IC3.12 (OUT10)
unnamed: 7.7 (4), IC3.11 (OUT11)
unnamed: 7.2 (3), IC3.10 (OUT12)
unnamed: 7.9 (2), IC3.9 (OUT13)
unnamed: 7.8 (1), IC3.8 (OUT14)
unnamed: 8.3 (7), IC3.6 (OUT16)
unnamed: 8.4 (6), IC3.5 (OUT17)
unnamed: 8.5, IC3.4 (OUT18)
unnamed: 8.7 (4), IC3.3 (OUT19)
unnamed: 8.2 (3), IC4.26 (OUT0)
unnamed: 8.9 (2), IC4.25 (OUT1)
unnamed: 8.8 (1), IC4.24 (OUT2)
unnamed: 9.3 (7), IC4.22 (OUT4)
unnamed: 9.4 (6), IC4.21 (OUT5)
unnamed: 9.5, IC4.20 (OUT6)
unnamed: 9.7 (4), IC4.19 (OUT7)
unnamed: 9.2 (3), IC4.18 (OUT8)
unnamed: 9.9 (2), IC4.17 (OUT9)
unnamed: 9.8 (1), IC4.12 (OUT10)
unnamed: 10.3 (7), IC4.10 (OUT12)
unnamed: 10.4 (6), IC4.9 (OUT13)
unnamed: 10.5, IC4.8 (OUT14)
unnamed: 10.7 (4), IC4.7 (OUT15)
unnamed: 10.2 (3), IC4.6 (OUT16)
unnamed: 10.9 (2), IC4.5 (OUT17)
unnamed: 10.8 (1), IC4.4 (OUT18)
unnamed: IC1.2 (DOUT), IC2.27 (DIN)
unnamed: IC2.2 (DOUT), IC3.27 (DIN)
unnamed: IC3.2 (DOUT), IC4.27 (DIN)
unnamed: IC1.27 (DIN), IN.2
unnamed: IN.10, L1.4-DIN (DIN)
unnamed: L10.2-DOUT (DOUT), OUT.10
unnamed: IC4.2 (DOUT), OUT.2
unnamed: IC1.15 (CLK), IC2.15 (CLK), IC3.15 (CLK), IC4.15 (CLK), IN.4, OUT.4
unnamed: IC1.16 (LOAD), IC2.16 (LOAD), IC3.16 (LOAD), IC4.16 (LOAD), IN.6, OUT.6
unnamed: 5.6 (HT+), R5.1
unnamed: IC1.13 (BLANK), IC2.13 (BLANK), IC3.13 (BLANK), IC4.13 (BLANK), IN.8, OUT.8
unnamed: 4.6 (HT+), R4.1
unnamed: 3.6 (HT+), R3.1
unnamed: 2.6 (HT+), R2.1
unnamed: 1.6 (HT+), R1.1
unnamed: 9.6 (HT+), R9.1
unnamed: 10.6 (HT+), R10.1
unnamed: 8.6 (HT+), R8.1
unnamed: 7.6 (HT+), R7.1
unnamed: 6.6 (HT+), R6.1

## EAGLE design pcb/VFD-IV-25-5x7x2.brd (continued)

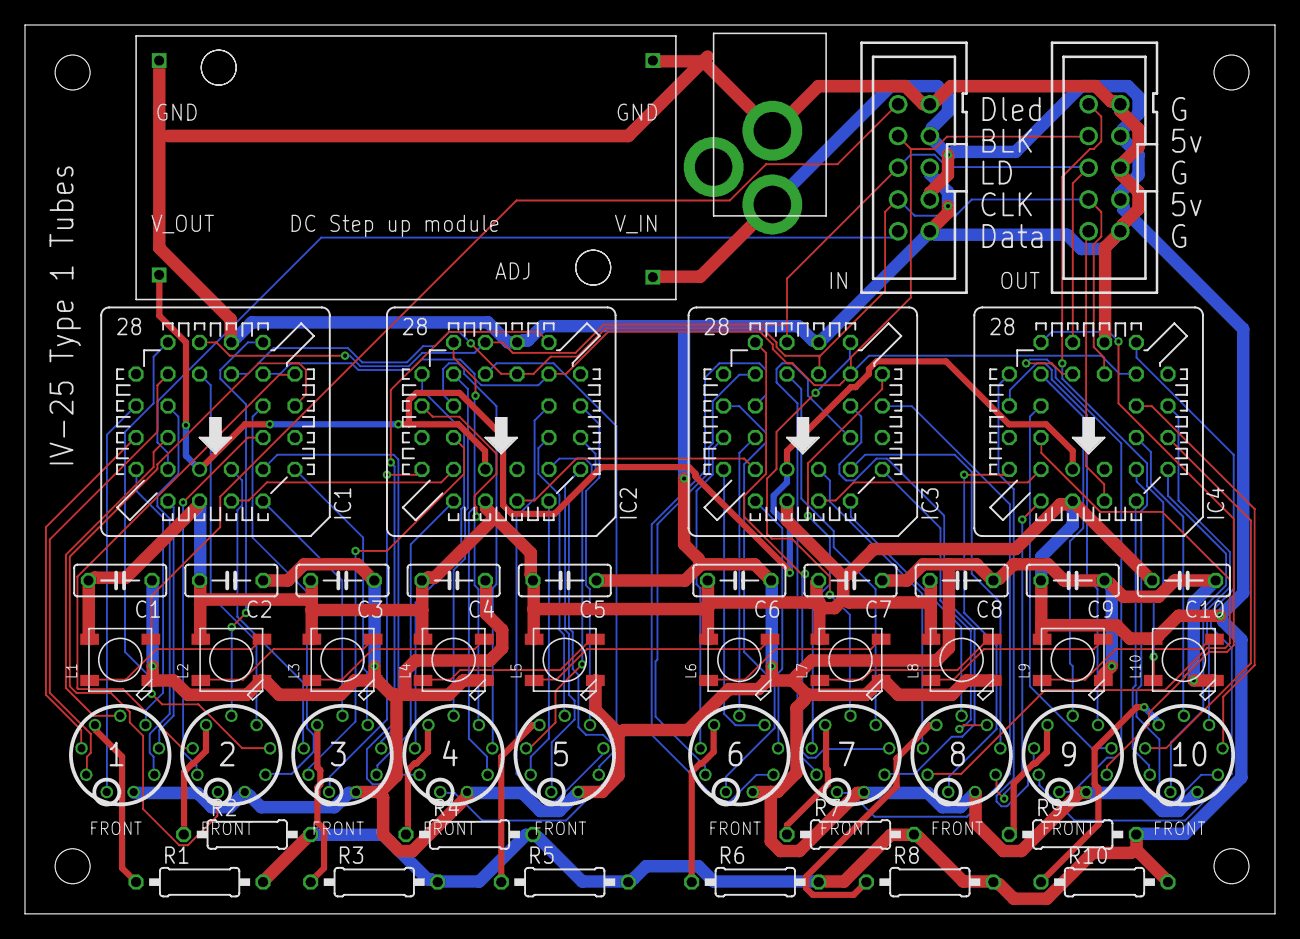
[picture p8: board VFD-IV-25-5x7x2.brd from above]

Board: 2 copper layers, 100.0 x 71.1 mm, 48 parts (0 on the bottom side), 102 nets.

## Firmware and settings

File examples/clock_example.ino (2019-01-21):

/*********************************************************************

  Ticking clock example for Wemos D1 Mini

  by Rob Jennings  07/01/2019
  
  also includes very simple web page to show that wifi stack is running
  the web page is really rough cut streaming direct out the HTTP

  the AP usually defaults to 192.168.4.1
  so join network and browse to that and tada ... 
  
*********************************************************************/


#include <ESP8266WiFi.h>
#include <WiFiClient.h> 
#include <ESP8266WebServer.h>
#include <ESP8266HTTPUpdateServer.h>
/* you need to install a library ... TimeAlarms */
/* look at library   Time   by the same author for NTP and other utilities */
#include <Time.h>
#include <TimeAlarms.h>


#define HOST_NAME  "simpleClock"
#define MY_AP_NAME "simpleClock"
#define MY_AP_PASS "needspassword"  /* 8 characters minimum on this string */

#define LONGEST_LOOP_TIME  100  /* 100ms longest wait in main ... */


ESP8266WebServer server ( 80 );
ESP8266HTTPUpdateServer httpUpdater;


bool showClock = true;  /* you might not want to sometimes */


/************************************************************* 
 *  
 * here is your regular tick task called every second
 * once all the setup in complete
 * 
*************************************************************/
void ticktask(void)
{
  static time_t time_local;  // read once or it might change while you are here
  static char time_string[20];   // static so you are not hammering the stack in and out of this routine

  time_local = now(); // sample the time


  /* do you want to show time or you might be doing something else eg RSS feed display */
  if(showClock)
  {
    
    /* notice I set up your serial port to 9600 ... same as smart sockets accept */
    /* so you could fiddle that string below to tell the time on your socket string !!! */
    /* BUT set them up first and turn off effects perhaps when scrolling */
    /* sprintf("$B7M%02d:%02d:%02d",hour(time_local),minute(time_local),second(time_local))    that would do it ! */

    sprintf(time_string,"Time %02d:%02d:%02d",hour(time_local),minute(time_local),second(time_local));
    Serial.println(time_string);

  }
  
  /* even if we are not showing the clock poll the http interface */
  /* once a second is sluggish you might poll this from your main loop instead? */
  /* but leaving it here is nice as gets done in 'background' to your other stuff */
  server.handleClient();
}




/************************************************************* 
 *  
 * all set up stuff
 * 
*************************************************************/
void setup()   
{
  
  Serial.begin(9600); /* same speed as smart sockets ... */
  
  /* let things settle down after boot */
  delay(100);
  /* introducing your very important yield command .... keep feeding the stack */
  yield;


  /* set up your sockets ? few of these with the right strings to set up your sockets and your away */
  /* Serial.println(" stuff "); */


  WiFi.hostname(HOST_NAME);
  WiFi.mode(WIFI_AP);
  WiFi.softAP(MY_AP_NAME, MY_AP_PASS);

  /* install 1 second tick tick timer */
  Alarm.timerRepeat(1, ticktask);

#ifdef DEBUG
  IPAddress myIP = WiFi.softAPIP();
  Serial.print(F("AP IP address: "));  // if I’m connected to something
  Serial.println(myIP);                // my IP as an access point otherwise 
#endif

  /* setup web page services */
  server.on ( "/", pageRoot );
  server.onNotFound ( handleNotFound );
  httpUpdater.setup(&server);
  server.begin();

#ifdef DEBUG
  Serial.println ( "HTTP server started" );
#endif


}





/************************************************************* 
 *  
 * main loop
 * 
 * could do all sort of stuff here ?
 * 
 * you MUST keep calling yield() to keep wifi alive and avoid watchdog
 *
 * you MUST use Alarm.delay(time) or the background tick process can’t run
 *
**************************************************************/

void loop()
{

  Serial.println("main loop starts ...");
  
  /* maybe you want to do NTP and RSS read or something */
  /* your clock is not set so will run from 00:00:00 */

  while(1)
  {

    yield(); /* each loop yield so that ESP does not crash */
    
    /*
      do your exciting stuff here !!!
      BUT don’t take too long doing it
      always yield() frequently if you must take a long time to do things
      and ALWAYS use Alarm.delay() instead of delay() so that tick can run
    */
    
    
    Alarm.delay(LONGEST_LOOP_TIME);  /* give other tasks time */
    
    /* busy doing nothing ... working the whole day through */
    /* trying to find lots of things not to do */
  }

}

/* web server root page */
void pageRoot() 
{
  static time_t time_local;  // might change while we spit out page
  static char time_string[20];   // static so you are not hammering the stack in and out of this routine

  time_local = now();

  sprintf(time_string,"Time %02d:%02d:%02d",hour(time_local),minute(time_local),second(time_local));
  
  server.setContentLength(CONTENT_LENGTH_UNKNOWN);
  server.send(200, F("text/html"), F("")); // Empty content inhibits Content-length header so we have to close the socket ourselves.
  server.sendContent(F("<html><head><meta http-equiv=\"refresh\" content=\"10\"><title>Simple Clock by Rob</title></head><body><h1>simple clock by Rob running</h1>"));
  server.sendContent( F("<p><h2>") );
  server.sendContent( time_string );
  server.sendContent( "</h2>" );
  
  server.sendContent( F("</body></html>") );
  server.client().stop(); // Stop is needed because we sent no content length

}


/* web server bad page */
void handleNotFound() 
{
  server.setContentLength(CONTENT_LENGTH_UNKNOWN);
  server.send(200, F("text/html"), F("")); // Empty content inhibits Content-length header so we have to close the socket ourselves.
  server.sendContent(F("<html><head></head><body><h1>404 Page Not Found</h1>"));
  server.sendContent( F("<p>URI: ") );
  server.sendContent( server.uri() );
  server.sendContent( F("</p><p>Method: ") );
  server.sendContent( ( server.method() == HTTP_GET ) ? "GET" : "POST" );
  server.sendContent( F("</p><p>Arguments: </p>") );

  for ( uint8_t i = 0; i < server.args(); i++ ) 
  {
    server.sendContent( F("<p>"));
    server.sendContent( server.argName(i) );
    server.sendContent( F(" : "));
    server.sendContent( server.arg(i) );
    server.sendContent( F("</p>"));
  }

  
  server.sendContent( F("</body></html>") );
  server.client().stop(); // Stop is needed because we sent no content length

}
